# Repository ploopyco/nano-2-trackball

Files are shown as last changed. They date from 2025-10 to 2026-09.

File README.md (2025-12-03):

# The Ploopy Nano 2 Trackball

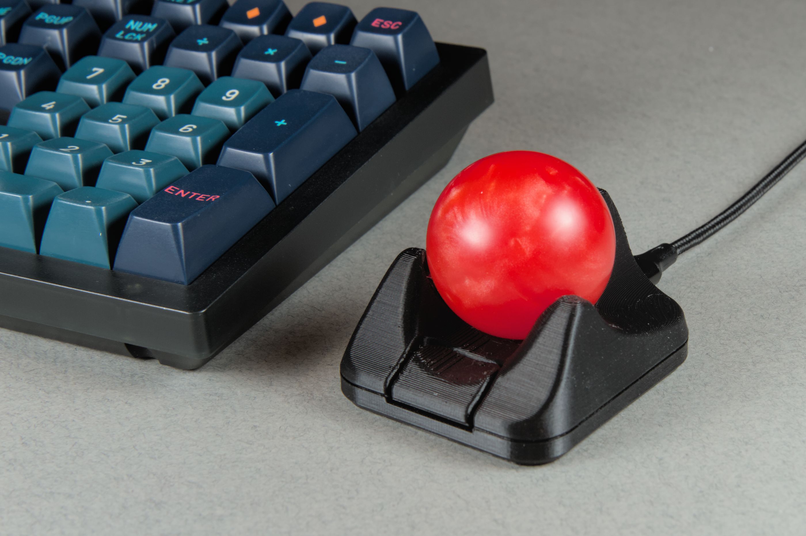
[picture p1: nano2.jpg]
The Ploopy Nano 2 Trackball


By some stroke of luck, you've made your way here. The Ploopy Nano 2 Trackball. Your life will never be the same.

This repository contains all of the design and production files necessary to make a Ploopy Nano 2 Trackball. We've also included some kick-ass documentation on how to get it made, assemble it, and program it [which you can find here](https://ploopyco.github.io/nano-2-trackball/).

What are you waiting for? Your new life awaits.

## QMK?!

Nano 2's bought from the [Ploopy store](https://ploopy.co/shop/nano-2-trackball/) come with QMK preloaded. [Check out the documentation](https://ploopyco.github.io/nano-2-trackball/) for instructions on how to load new firmware onto your device. (It's super easy!)

The firmware file that ships with all Nano 2's is included in this repository as well, as `firmwares/nano2_natural_dragscroll_toggle.uf2`.

## Under what license is this released?

As per QMK's licensing requirements, the firmware for the Ploopy Nano 2 Trackball is released under GPLv3. Hardware design files, including electronics and mechanical files, are released under OHL CERN v2-S. Check the respective directories for full license text.

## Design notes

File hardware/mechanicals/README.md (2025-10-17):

## Only one file? Where are the parts?

The STEP/STL files contain all of the plastic parts in one file. Doing it this way preserves the assembly information, showing how the parts are supposed to fit together, as well as the expected clearances between parts. It also bundles all of the parts for a given revision together, so there's no accidental mixing of parts from different revisions.

## How do I print this?

You'll need to split the parts in the file up before you can print them. Most slicers can do this; if you have a compatible printer we recommend PrusaSlic3r, since that's the one we use in-house and have checked.

Note that submitting this file to some 3rd party print services will cause confusion, as they are expecting one body instead of many. To do this, you can use PrusaSlic3r to split the parts and then export each separately as an STL.

## How can I use the included .3mf file?

The .3mf file was generated using PrusaSlicer v2.9. The job was generated for Prusa i3 MK2S/MK3S/MK3S+ printers. It assumes the use of PLA that is printable at 200-230C. If you have that PrusaSlicer version, such a printer, and such filament, then you're in a lot of luck! We use a .3mf job that is very similar to this one to print these parts on our printing farm.

If you do not, then using the included .3mf file is likely going to cause you a lot of headaches. If this is the case, the included .3mf file should be considered **as a reference only**. If you use it at all, it is recommended that you look at it to see what kinds of print settings we use (gyroid infill, 0.3mm layer height, part orientation, etc.). However, you should use your own slicing software to generate the .gcode files for your printer.

## Why don't you include a .gcode file?

For your safety. Uploading a .gcode file onto a printer can be extremely hazardous if that .gcode file wasn't specifically generated for that printer. We don't want to come anywhere near that sort of scenario, so we are not going to upload a .gcode file.

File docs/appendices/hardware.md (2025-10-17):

# Appendix C: Hardware

## Buying hardware from us

Getting all of the hardware on your own can be tricky because the parts you select may not fit perfectly. [That's why we sell fully-assembled Nano 2's](https://ploopy.co/shop/nano-2-trackball/). Here's why that's great for you:

- Everything is guaranteed to fit together perfectly
- Everything is guaranteed to work as intended
- You'll end up saving money - probably quite a bit of money - by not spending on extra parts

Your call. You'll sort it out.

## Getting your own hardware

This guide was a bit light on detail in the other sections, and that's because the hardware has to conform to many specifications. They'll all be listed here.

First, a complete list of all the hardware you'll need:

- \#2 3/8" screws, x2
- MR63ZZ roller bearings, x3
- Friction pads, x4
- 1.5" ball

We'll be going over all of them in detail. There will be mentions of *critical specifications*; if you're going to be sourcing your own parts, **you must get parts that conform to the critical specifications**. If you go off-menu, the parts will not fit the way that we intended when we designed the Nano 2. That might mean that your Nano 2 **doesn't work**.

Let's get cracking.

### Screws

Here are the critical specifications:

- \#2
- 3/8" length

## MR63ZZ roller bearings
Here are the critical specifications:

- MR63ZZ bearing
- 3mm inner diameter
- 6mm outer diameter
- 2.5mm thickness

### Friction pads

Here are the critical specifications:

- Circular shape
- Up to 3/4" diameter
- Up to 1/8" thickness
- Non-slip

## 1.5" ball

We use a 1.5-inch diameter (38.00) balls. Any ball that is within 0.5mm in diameter should work.

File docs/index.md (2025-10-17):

# Home

So, you want to build a Ploopy Nano 2 Trackball, eh? Or, maybe you want to replace some broken parts. Maybe you want to reprogram it. Or maybe you just want to know how it all works. No matter the motivation, this is the place to learn.

**Sourced the parts and itching to get it built?** --> Get started by going to the [assembly instructions](assembly-instructions.md).

**Looking to purchase your own Nano 2?** --> [Check out the Ploopy store](https://ploopy.co/shop/nano-2-trackball/).

**Building a Ploopy Nano 2 from scratch?** --> Get started by going to [Appendix A: Printed circuit boards](appendices/pcbs.md).

---

*Copyright (C) 2025 Ploopy Corporation. Permission is granted to copy, distribute and/or modify this document under the terms of the GNU Free Documentation License, Version 1.3 or any later version published by the Free Software Foundation; with no Invariant Sections, no Front-Cover Texts, and no Back-Cover Texts. A copy of the license is included in the section entitled "GNU Free Documentation License".*

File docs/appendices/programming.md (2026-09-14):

# Appendix D: QMK Firmware Programming

## Working with QMK

Ploopy devices are fairly easy to program and reprogram, thanks to the excellent work by all of the developers and maintainers of the [QMK firmware suite](https://github.com/qmk/qmk_firmware).

## Before you begin

If you have never used QMK before, go through [all of the steps in the QMK guide to set up your environment](https://docs.qmk.fm/#/newbs_getting_started).

QMK was built for keyboards, so you'll see lots of references to code that looks like the following:

`-kb <keyboard>`

Whenever you see that, use the following syntax:

`-kb ploopyco/nano_2`

and you'll be fine.

## Building the Ploopy device firmware

Using QMK MSYS or your compilation toolchain of choice, compile the firmware with the following command:

`qmk compile -kb ploopyco/nano_2/rev2_003 -km default`

For more details on building QMK firmware in general, see the [QMK firmware guide](https://docs.qmk.fm/#/newbs_building_firmware).

## Putting the Ploopy device into bootloader mode

Putting the Ploopy device into bootloader mode is very easy.

1. Unplug it from your computer.
2. Hold down the button on the Nano 2.
3. Plug the Ploopy device into your computer.
4. The computer should recognise that a mass storage device was just plugged in. Once this is done, you should be able to drag and drop files onto the Ploopy device, as if the board was a USB drive.

And that's it. While plugged in this way, the Ploopy device will accept new firmware.

If you want to upload a new firmware file (a ".uf2" file, like "ploopy_nano2_v42069" or something), just drag it into the folder, and it'll automatically install on the Ploopy device and restart itself.

Whenever you want to put new firmware onto the Ploopy device, go through these steps again.

**TIP**: If your firmware is in some kind of strange state and uploading new firmware isn't fixing it, try uploading [a flash nuke](https://learn.adafruit.com/getting-started-with-raspberry-pi-pico-circuitpython/circuitpython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) to the Nano 2 before flashing the new firmware. It wipes the memory of the Nano 2 completely clean, which can help clear a few types of errors.

## Putting the Ploopy device into bootloader mode if it's bricked

Putting the Ploopy device into bootloader mode if it's bricked is a bit more involved, but still doable.

1. Unplug it from your computer.
2. Open it by removing the screws in the Base and removing the Top.
3. Look for a pair of vias (gold-plated holes) on the board ([here's a photo](../img/bl.jpg)).
4. Get a paper clip (non-insulated, i.e. no plastic shit covering it) or a pair of tweezers, or some wire. Whatever you've got on hand that's metal.
5. Stick the paper clip or tweezers into the holes. You're trying to form an electrical connection between the two holes.
6. While you've got the two vias connected with your metal bridge, plug the Ploopy device into your computer.
7. The computer should recognise that a mass storage device was just plugged in. Once this is done, you should be able to drag and drop files onto the Ploopy device, as if the board was a USB drive. Feel free to remove the tweezers or paperclip at this point.

And that's it. While plugged in this way, the Ploopy device will accept new firmware.

## And that's it!

Happy customizing!

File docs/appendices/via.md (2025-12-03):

# Appendix E: Using VIA

The Nano 2's button can be customized using a web application called "VIA". Currently, a bit of additional work is necessary to get VIA to work, but it should only take about thirty seconds.

Begin by copying and pasting the following into a text file, saving it as *nano2.json*:

    {
      "name": "Ploopy Nano 2 Trackball",
      "vendorId": "0x5043",
      "productId": "0x4CE5",
      "matrix": {
        "rows": 1,
        "cols": 1
      },
      "customKeycodes": [
        {
          "name": "DPI Config",
          "title": "DPI Config",
          "shortName": "DPI"
        },
        {
          "name": "Drag Scroll",
          "title": "Drag Scroll",
          "shortName": "DragScl"
        }
      ],
      "layouts": {
        "keymap": [
          [
            {
              "h": 2
            },
            "0,0"
          ]
        ]
      }
    }

- Next, navigate to [the VIA web app](https://usevia.app), using **Microsoft Edge, Chrome, or Opera**. Any other browser that supports WebHID will work, too.
- Look at the top toolbar of the web application, and click the tab called *DESIGN*.
- Uncheck *Use V2 definitions (deprecated)*.
- Click *Load* and upload the *nano2.json* file that you saved on your computer.
- Plug in the Nano 2 if it wasn't plugged in already.
- Look at the top toolbar of the web application, and click the tab called *CONFIGURE*.
- Click *Authorize Device*. A modal window should pop up, and you should see the *Ploopy Nano 2 Trackball* as an option to connect. Do so now.

You should now see a representation of the buttons of the Nano 2 in the web app. You are now free to modify the button's functionality.

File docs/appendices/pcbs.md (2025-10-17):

# Appendix A: Printed circuit boards

## Buying boards from us
Getting the Ploopy boards made can be complex, and expensive, especially if you only need one set. [That's why we sell fully-assembled Nano 2's](https://ploopy.co/shop/nano-2-trackball/). Here's why that's great for you:

- You get a PCB with all components soldered
- The firmware is already programmed on the microcontroller, so you won't have to program it
- It'll cost a hell of a lot less than if you do a production run of PCBs just for yourself
- You won't have to order components and wait while they come in
- We guarantee that it works

Just something to consider. You're smart. You'll figure it out.

## Making your own boards

Want to make your own Ploopy Nano 2 Trackball boards? Great! Less work for us. Seriously, though, only choose this option if you know what you're doing. You don't want to embarrass yourself, do you?

### Step 1: Order the PCBs from a PCB production company

Here are the most important configurations you'll need to communicate to the company:

- 4 layers
- FR-4, TG 150-160 (basically, whatever the cheapest option is)
- 1.6mm thickness
- 6/6mil track/spacing distance
- 0.3mm minimum hole size
- ENIG surface finish, but you can go with HASL if you don't care about lead poisoning
- 1oz copper thickness for both outer and inner layers
- Choose whatever colours you want for solder mask and silkscreen; we like green solder mask and white silkscreen

If something is missing from here, it's not really important.

At some point, you'll have to upload design files to the production company. Use the [electronics source files](https://github.com/ploopyco/nano-2-trackball/tree/master/hardware/electronics) to generate manufacturing files (you'll have to convert them from their native Altium format if you're using some other platform). That should contain everything you need to get the boards made. If the production company rejects this package, however, you'll need to address the issue yourself.

### Step 2: Order the electronics components

All of the components are described in the schematics of the PCBs. Ordering the components is left as an exercise for the reader.

A complete list of all of the components can be found in the electrical design files.

### Step 3: Get the necessary tools

- PCB
- All of the electronics components
- A hot air rework tool
- Solder paste
- A printout of the schematics

### Step 4: Solder the components to the boards

Once you've got the PCBs and all of the components, print out the schematics. Use the schematics to match the reference designators on the PCBs to the reference designators on the schematics, and then get to soldering.

If you've never soldered surface mount components before, or want a refresher on how to solder, we recommend [this video on using an iron to solder surface mount components](https://www.youtube.com/watch?v=3NN7UGWYmBY), and [this video on using a hot-air soldering station](https://www.youtube.com/watch?v=c_Qt5CtUlqY).

### Step 5: All done!

Congrats, you finished assembling the electronics! Pat yourself on the back.

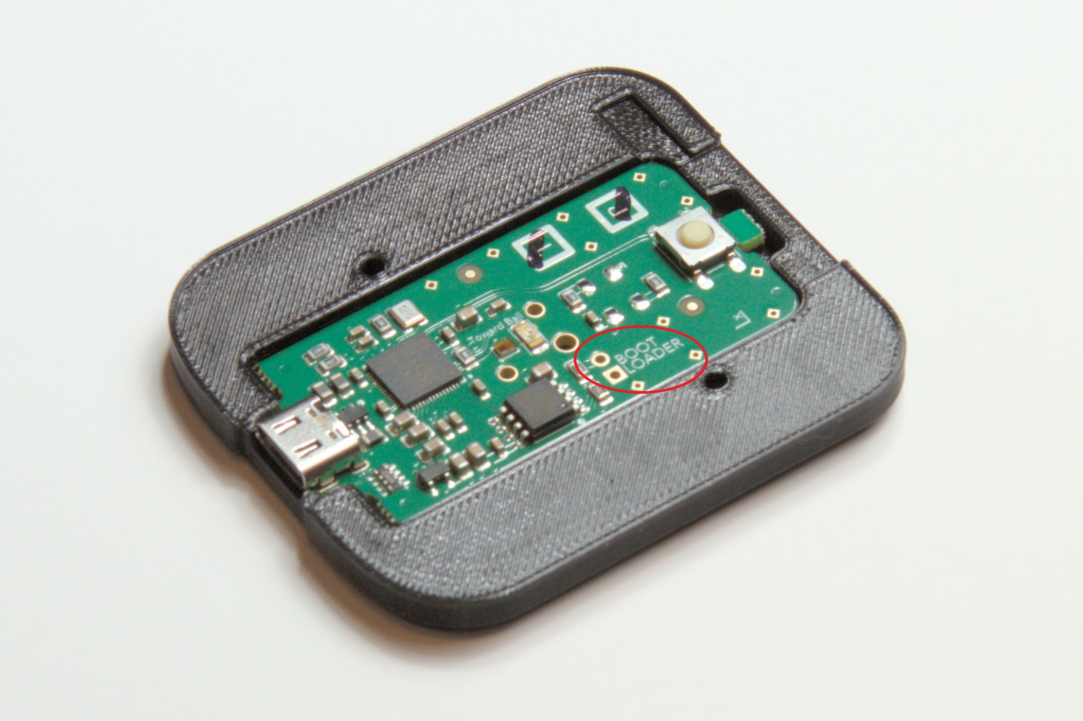
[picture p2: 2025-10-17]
docs/img/bl.jpg

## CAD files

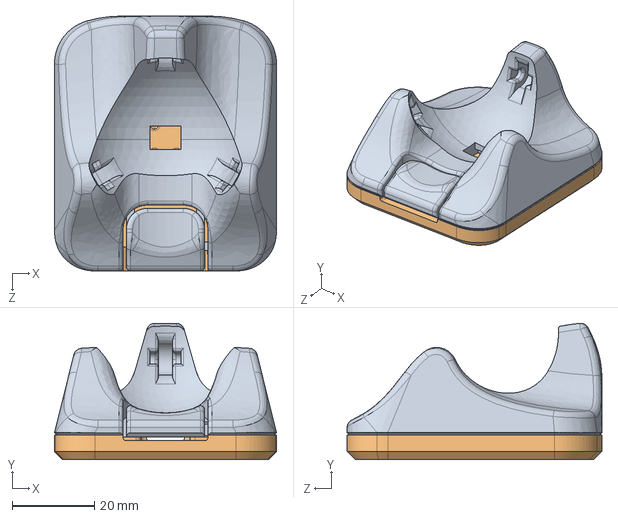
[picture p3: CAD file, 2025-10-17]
hardware/mechanicals/nano2.STEP
54.0 x 33.2 x 62.0 mm

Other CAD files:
hardware/mechanicals/nano2.3mf
hardware/mechanicals/nano2.STL

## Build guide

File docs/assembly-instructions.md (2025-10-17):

# Ploopy Nano 2 Trackball Assembly Instructions

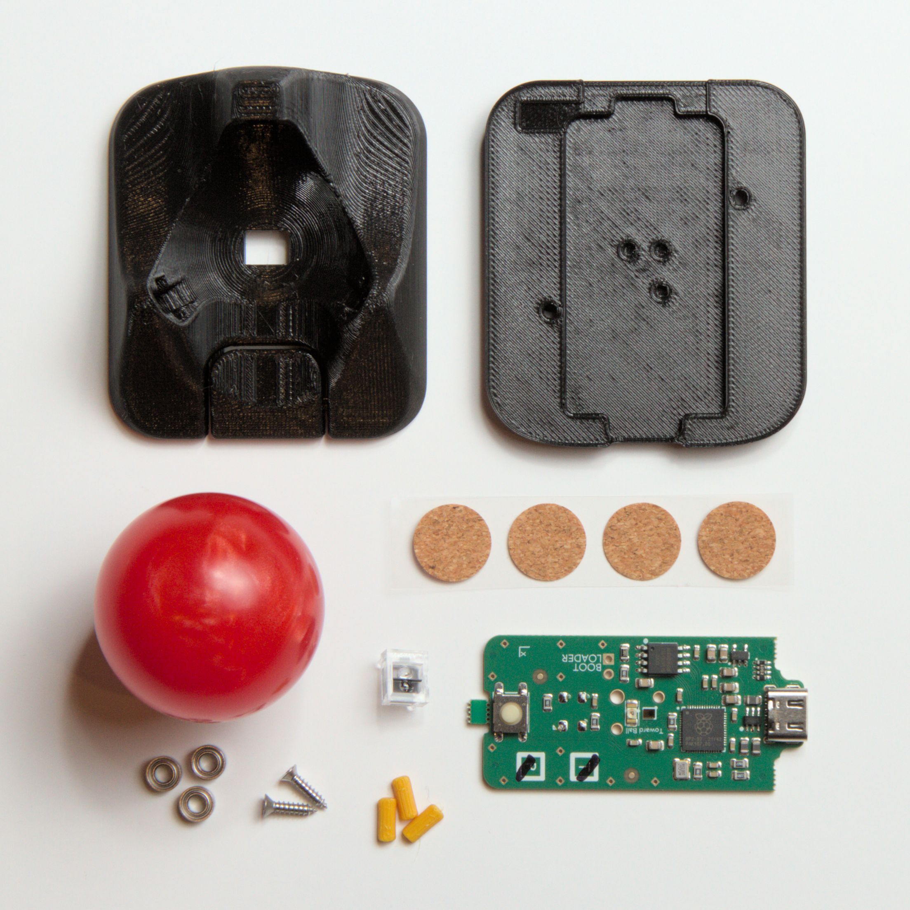
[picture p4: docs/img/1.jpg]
|  |
|:--:|
| *Figure 1: Everything you'll need* |

## Main Instructions

In this section, you'll go over how to build a Ploopy Nano 2 Trackball. This assumes you've sourced the parts yourself following the designs in this repository.

Here's how these instructions are structured*:

- 💡 Comments with a lightbulb are good information to know.
- ➡️ Comments with an arrow are commands. Execute them when you encounter them.
- ✅ Comments with a checkmark are verification steps. Check what they tell you to check, and if it's all good, move on.
- 📷 Comments with a camera are references to photos. Check the corresponding image for guidance.

Most steps have photos, so if you need some additional visual help, consult the images.

*\* Thanks to [schneems](https://github.com/schneems) for his [great suggestions on how to write documentation](https://github.com/ploopyco/headphones/issues/37).*

### Step 1

- ➡️ Get the Bottom, the PCB, and the PCB Optic. 📷 *See Figure 2.*

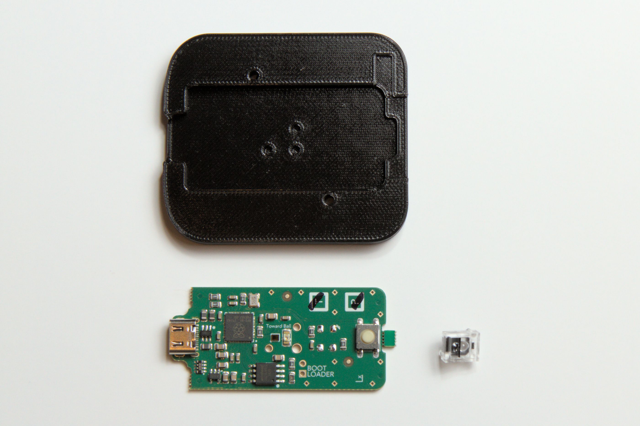
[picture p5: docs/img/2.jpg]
|  |
|:--:|
| *Figure 2: The Bottom, PCB, and PCB Optic* |

### Step 2

- 💡 In order to fit correctly, the PCB must be oriented correctly in the Bottom. 📷 *See Figure 3.*
- ➡️ Place the PCB into the Bottom.

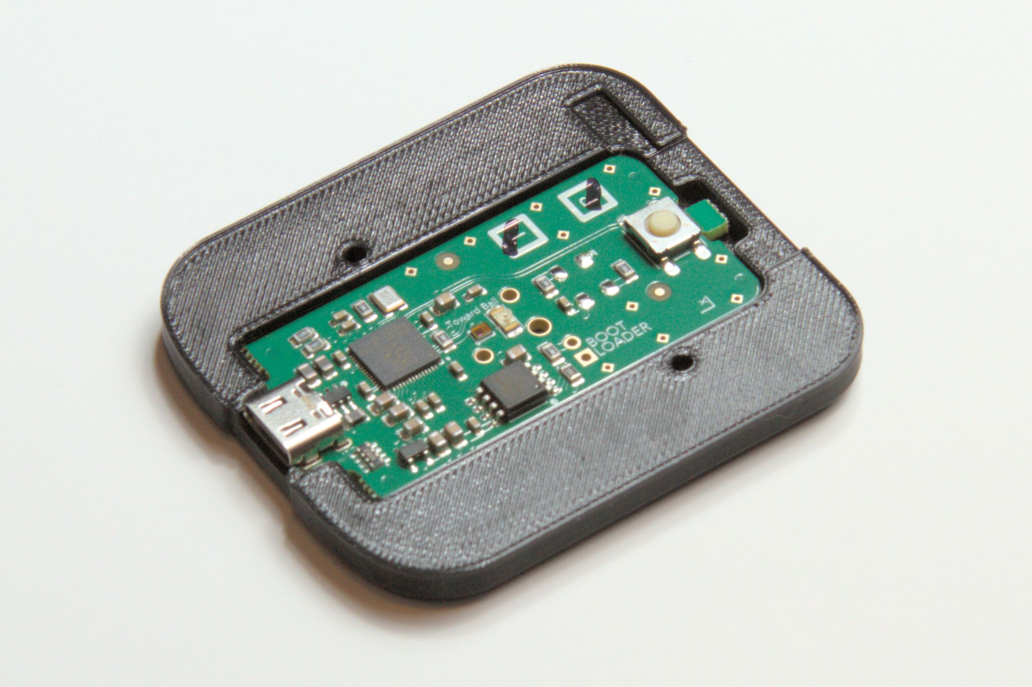
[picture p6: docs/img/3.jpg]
|  |
|:--:|
| *Figure 3: PCB correctly oriented in Bottom* |

### Step 3

- 💡 In order to fit correctly, the PCB Optic must be oriented correctly in the PCB. 📷 *See Figure 4 and Figure 5.*
- ➡️ Place the PCB into the Bottom.

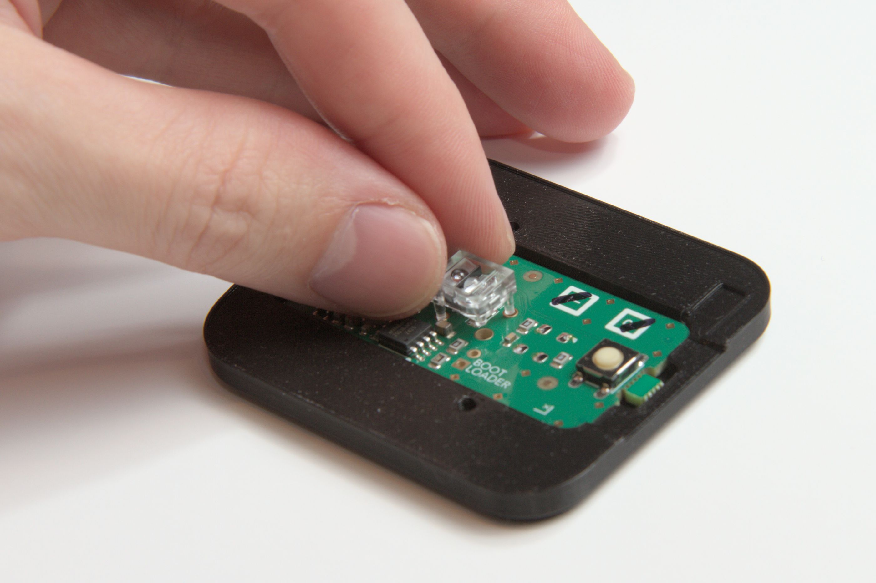
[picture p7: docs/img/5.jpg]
|  |
|:--:|
| *Figure 4: Preparing to insert PCB Optic* |

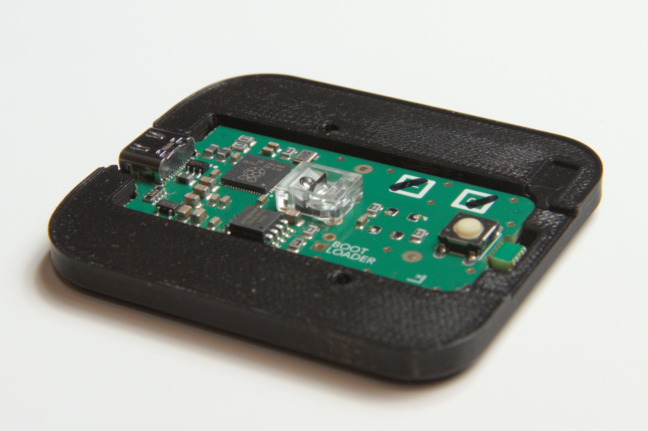
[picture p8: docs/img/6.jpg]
|  |
|:--:|
| *Figure 5: PCB Optic correctly oriented in PCB* |

### Step 4

- ➡️ Get the Top. 📷 *See Figure 6.*

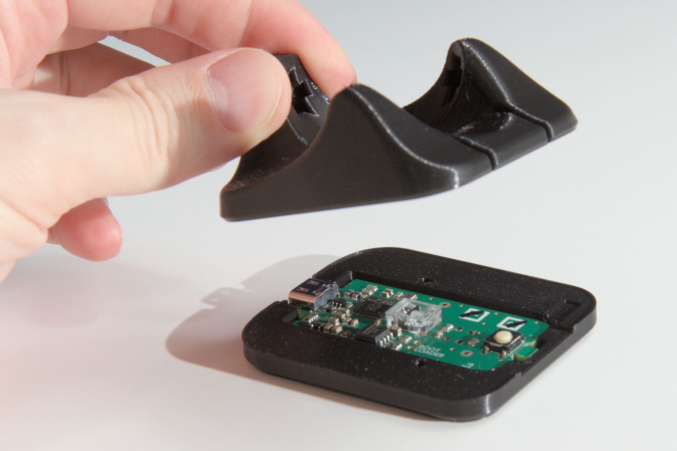
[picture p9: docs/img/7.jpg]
|  |
|:--:|
| *Figure 6: Top* |

### Step 5

- 💡 The Top has a flexible moving button mechanism. This mechanism must be oriented so that it is over the switch. 📷 *See Figure 6 again.*
- ➡️ Place the Top onto the Bottom assembly. 📷 *See Figure 7.*

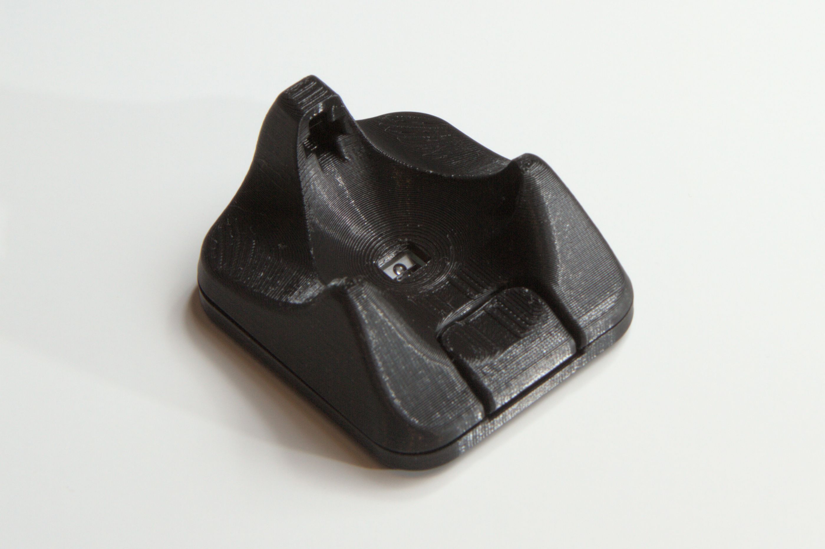
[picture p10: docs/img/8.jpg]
|  |
|:--:|
| *Figure 7: Top placed correctly on Bottom assembly* |

### Step 6

- ➡️ Get a #1 Phillips head screwdriver (or similar; you're looking for a small-ish screwdriver here).
- ➡️ Get the two screws. 📷 *See Figure 8.*
- ➡️ Screw in the two screws. 📷 *See Figure 9.*

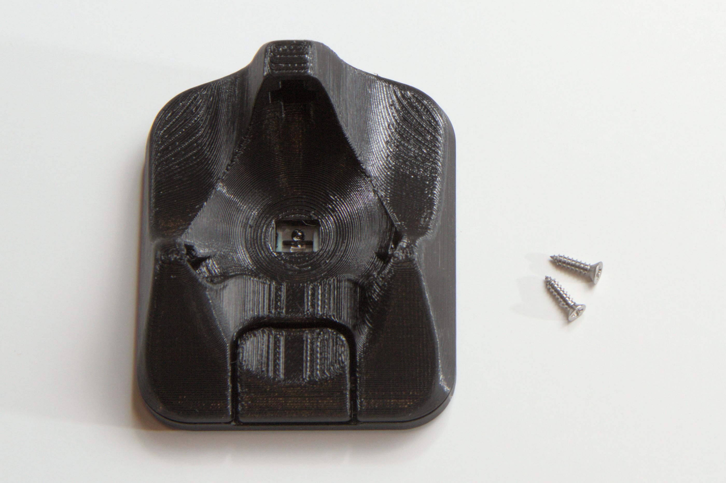
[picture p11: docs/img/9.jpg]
|  |
|:--:|
| *Figure 8: Two screws* |

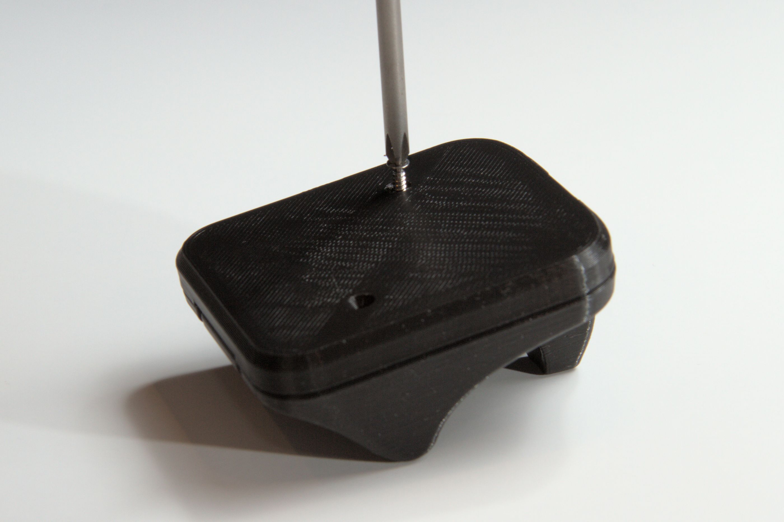
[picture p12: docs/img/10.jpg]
|  |
|:--:|
| *Figure 9: Screws being screwed down* |

### Step 7

- ➡️ Get the friction pads. 📷 *See Figure 10.*
- ➡️ Place the friction pads on the Bottom. 📷 *See Figure 11.*

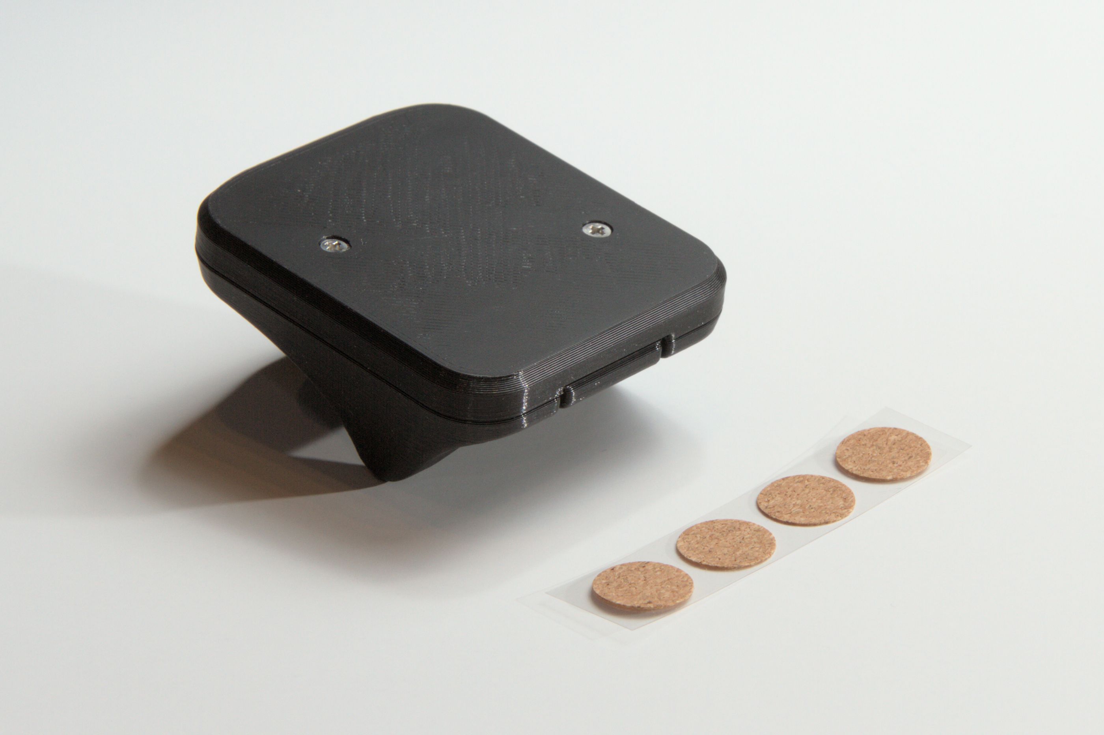
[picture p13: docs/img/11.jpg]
|  |
|:--:|
| *Figure 10: Four friction pads* |

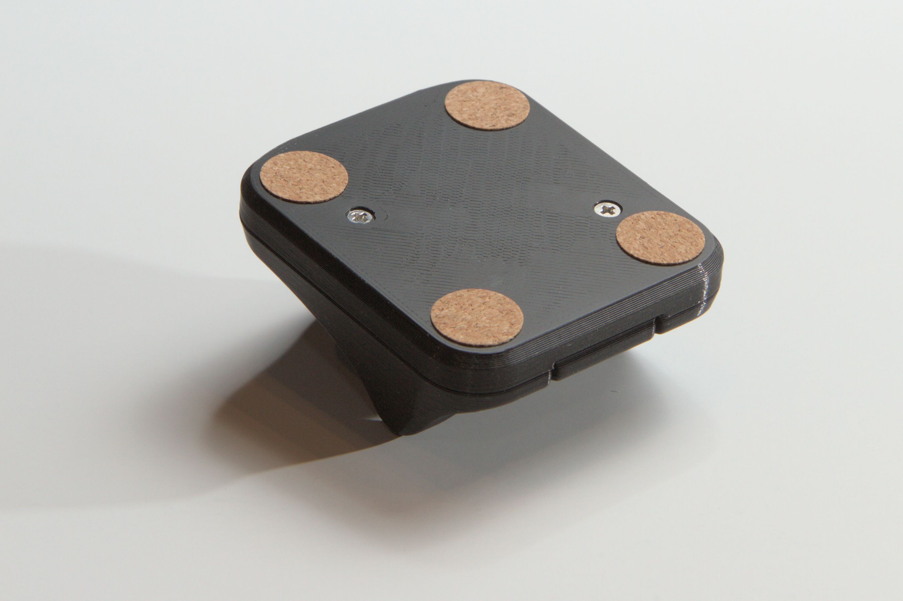
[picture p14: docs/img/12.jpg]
|  |
|:--:|
| *Figure 11: Four friction pads installed* |

### Step 8

- ➡️ Get 3x Roller Bearings, 3x Roller Bearing Dowels, and the Bearing Press Jig. 📷 *See Figure 12 for details.*
- ➡️ Insert a Roller Bearing and a Roller Bearing Dowel into the halves of the Bearing Press Jig. 📷 *See Figure 13 for details.*
- 💡 Pressing the halves of the Bearing Press Jig together may require a surprising amount of force.
- ➡️ Press the halves of the Bearing Press Jig together. 📷 *See Figure 14 for details.*
- ➡️ Remove the bearing from the Bearing Press Jig and repeat two more times for the other Roller Bearings. 📷 *See Figure 15 for details.*

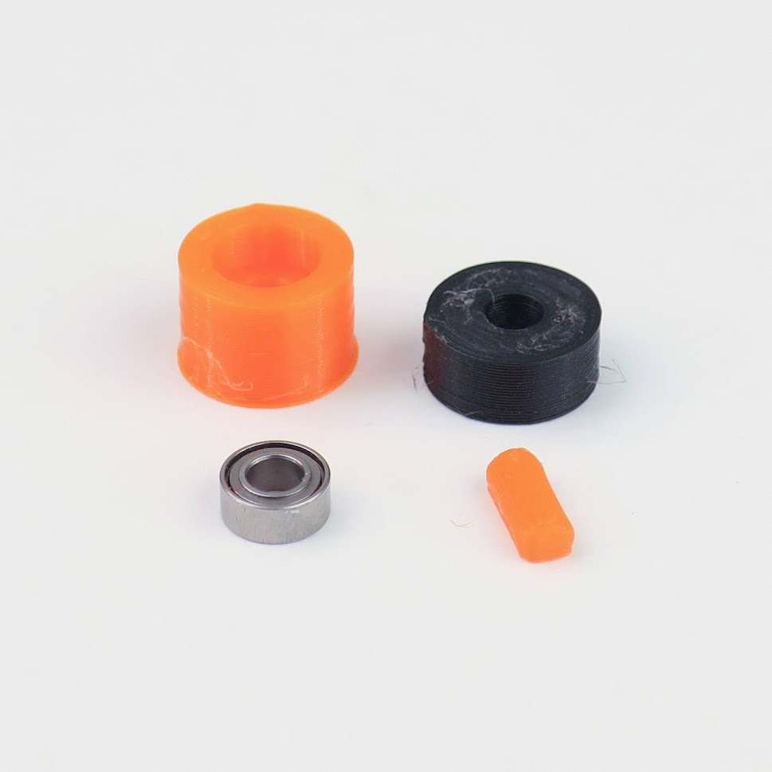
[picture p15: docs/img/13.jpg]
|  |
|:--:|
| *Figure 12: Roller Bearings, Roller Bearing Dowels, and the Bearing Press Jig* |

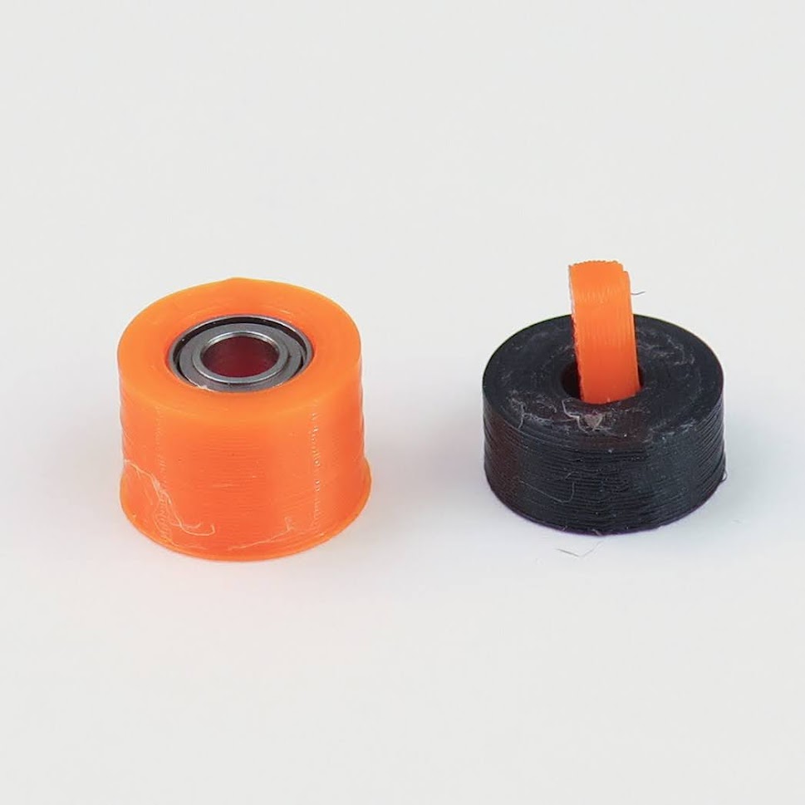
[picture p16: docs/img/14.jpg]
|  |
|:--:|
| *Figure 13: Roller Bearing and a Roller Bearing Dowel in the halves of the Bearing Press Jig* |

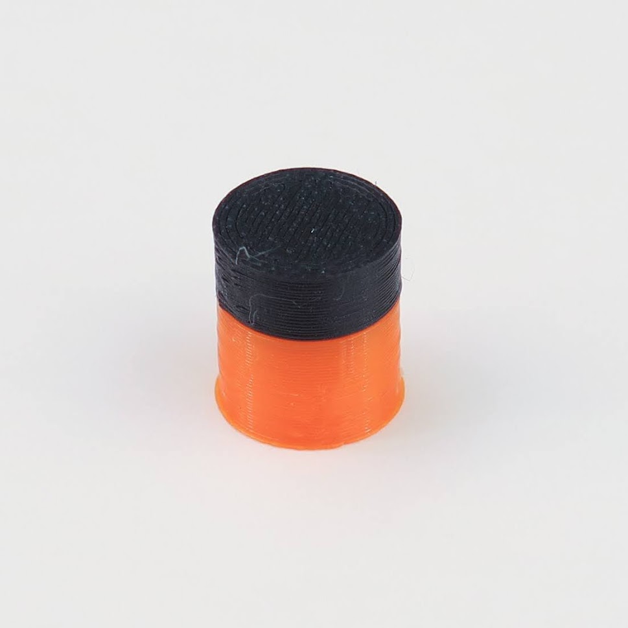
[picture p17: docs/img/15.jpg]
|  |
|:--:|
| *Figure 14: Halves of the Bearing Press Jig pressed together* |

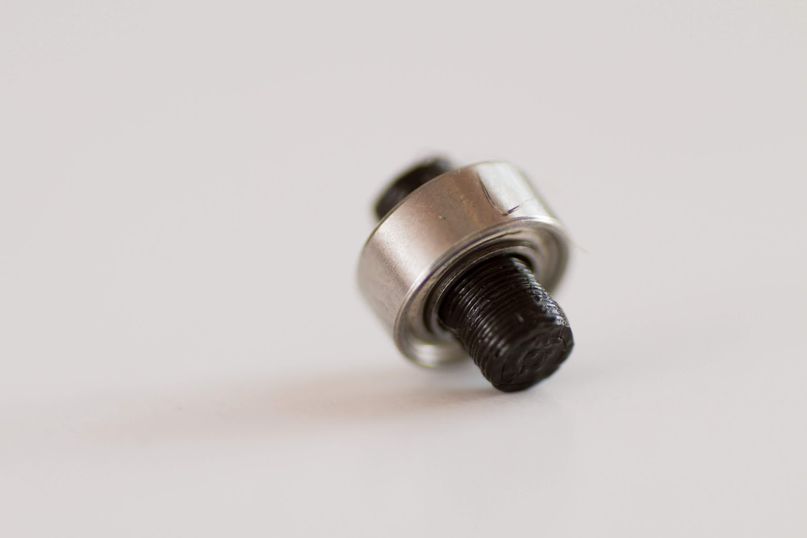
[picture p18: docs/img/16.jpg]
|  |
|:--:|
| *Figure 15: Completed Roller* |

### Step 9

- ➡️ Get the Top and 3x Rollers.
- 💡 Consider using needle nose pliers to press the Rollers into the Top as that will ensure that the Roller is fully seated.
- ➡️ Insert Rollers into the Top. 📷 *See Figure 16 for details.*
- 💡 If the Rollers aren't seated all the way, there's a good chance that tracking performance will be very bad.
- ✅ Ensure that the Rollers are pressed all the way into the Top, which may require quite a bit of force.

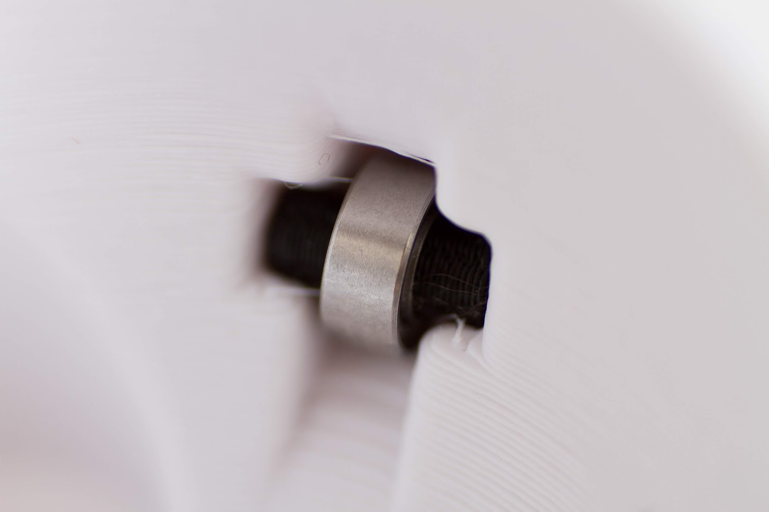
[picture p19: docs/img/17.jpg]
|  |
|:--:|
| *Figure 16: Roller inserted into Top* |

### Step 10

- ➡️ Insert the Ball. 📷 *See Figure 17 for details.*
- ➡️ Plug the Nano 2 into your computer.
- ✅ Check that moving the Ball moves the cursor.

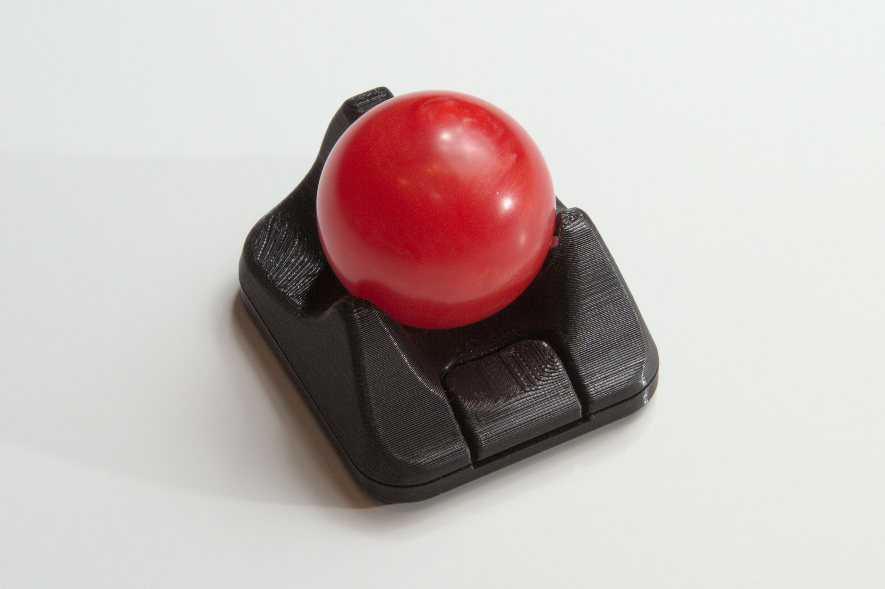
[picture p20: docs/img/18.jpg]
|  |
|:--:|
| *Figure 17: Ball inserted* |

### Step 16

- 💡 Congrats, you finished building the Ploopy Classic 2!
- 💡 It's done! Love it, use it, but don't you dare abuse it!

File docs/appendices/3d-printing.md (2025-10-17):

# Appendix B: 3D printed parts

## Buying 3D-printed parts from us

Not everyone has access to a 3D-printer. [That's why we sell fully-assembled Nano 2's](https://ploopy.co/shop/nano-2-trackball/). Here's why that's great for you:

- You get all of the 3D-printed parts, guaranteed free of manufacturing defects
- You won't waste time spending hours tweaking settings
- We guarantee it will fit together *perfectly*

Consider it. You're a smartie. You'll get there.

## Printing your own parts

So, you have a printer and want to print your own parts? Great! We don't have specific instructions, since every printer setup is different. All of the STLs are available, and if you need to make tweaks, you can alter the design files.

Here are the settings we use when we print parts. **Note that these settings have only been tested on the Prusa i3 MK2.5S and MK3S.** If you have another printer, you may need to tweak these settings.

- PLA. The geometry of many of the parts is quite complex; trying to use other materials may not result in success.
- 0.20mm layer height. You can go finer than this if you want, but we haven't tested that. Going coarser is not going to work; first, it's going to feel rough on your hand, and second, it won't accurately capture the necessary detail.
- No support material is necessary. If your slicer is showing support material, you didn't orient the parts correctly.
- Orient the pieces so that flat sides are on the build plate.
- We like gyroid for infill pattern, but anything is probably good. Cubic, rectilinear, whatever.
- We use 0.4mm nozzles. We haven't tested other nozzle sizes.

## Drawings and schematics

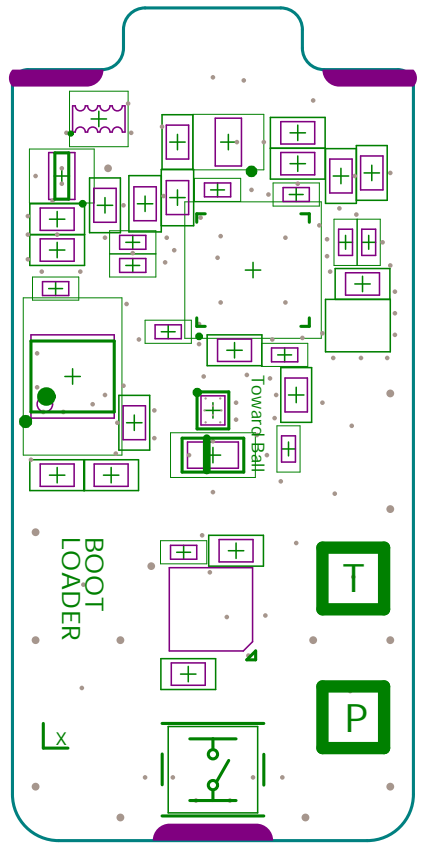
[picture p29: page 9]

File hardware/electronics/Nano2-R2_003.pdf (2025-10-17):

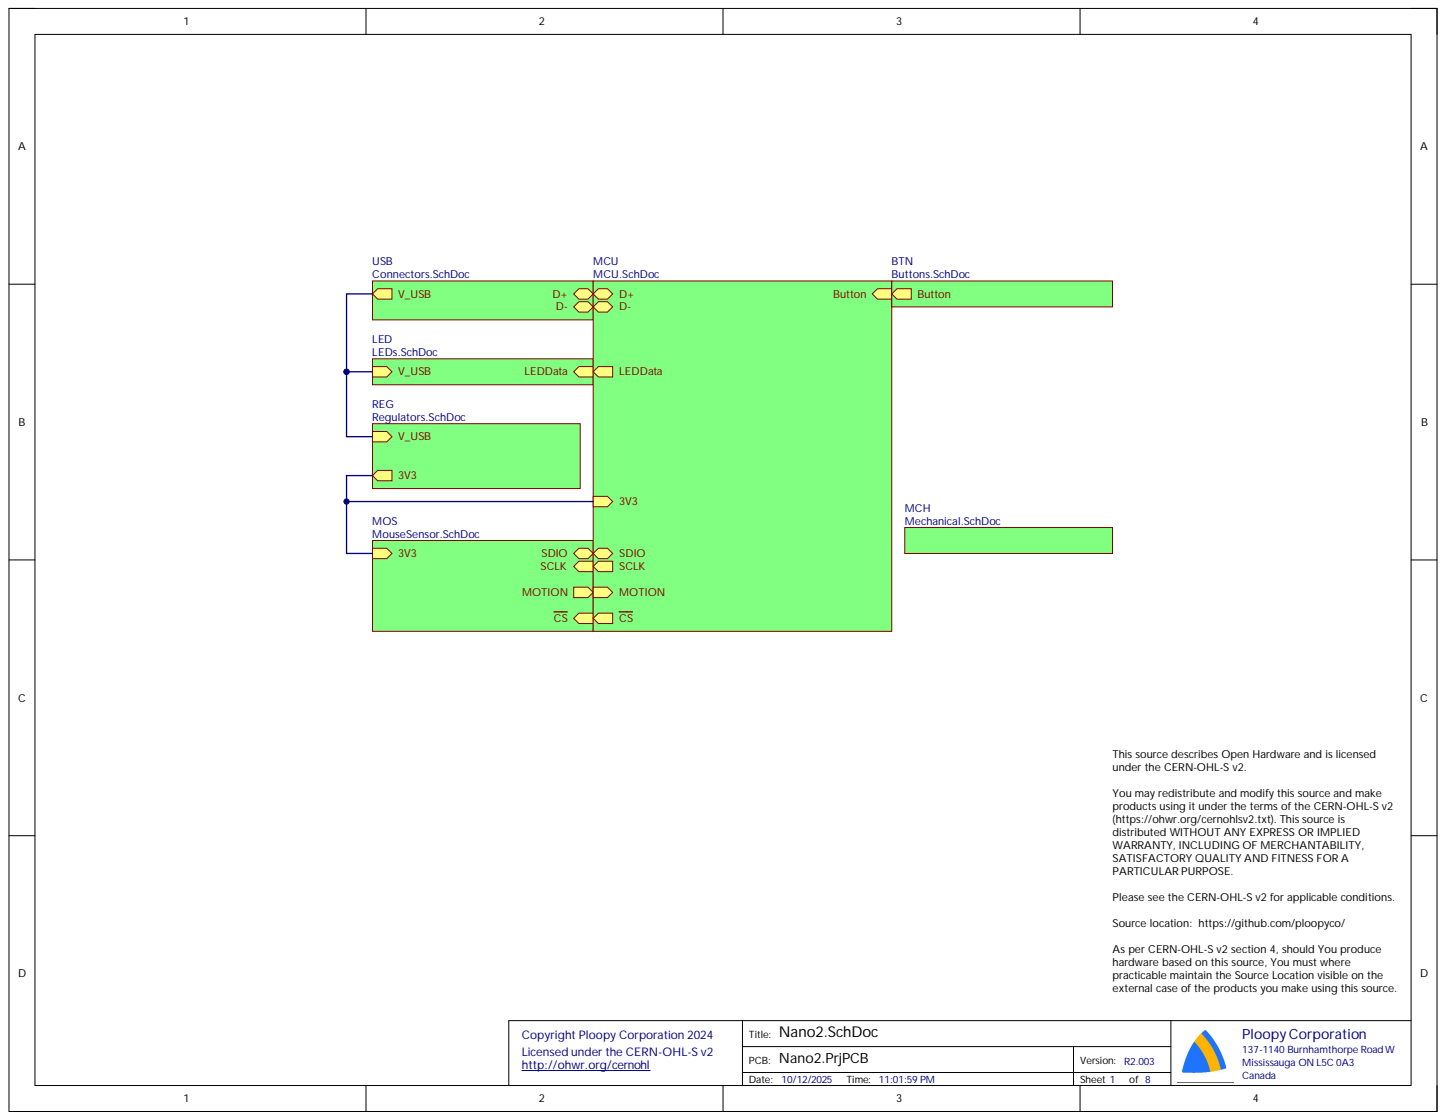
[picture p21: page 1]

This source describes Open Hardware and is licensed
under the CERN-OHL-S v2.

You may redistribute and modify this source and make
products using it under the terms of the CERN-OHL-S v2
(https://ohwr.org/cernohlsv2.txt). This source is
distributed WITHOUT ANY EXPRESS OR IMPLIED
WARRANTY, INCLUDING OF MERCHANTABILITY,
SATISFACTORY QUALITY AND FITNESS FOR A
PARTICULAR PURPOSE.

Please see the CERN-OHL-S v2 for applicable conditions.

Source location: https://github.com/ploopyco/

As per CERN-OHL-S v2 section 4, should You produce
hardware based on this source, You must where
practicable maintain the Source Location visible on the
external case of the products you make using this source.

Copyright Ploopy Corporation 2024
Licensed under the CERN-OHL-S v2
http://ohwr.org/cernohl

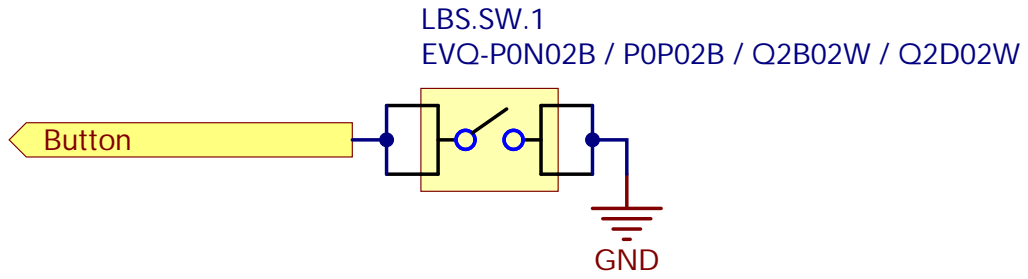
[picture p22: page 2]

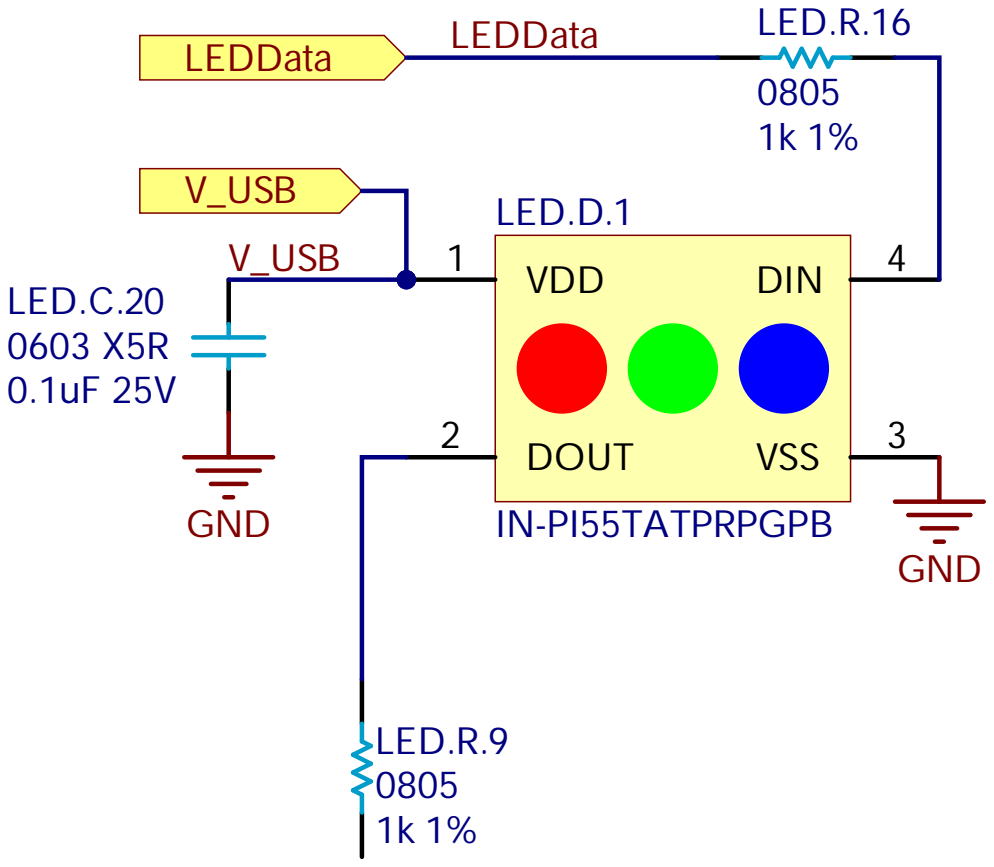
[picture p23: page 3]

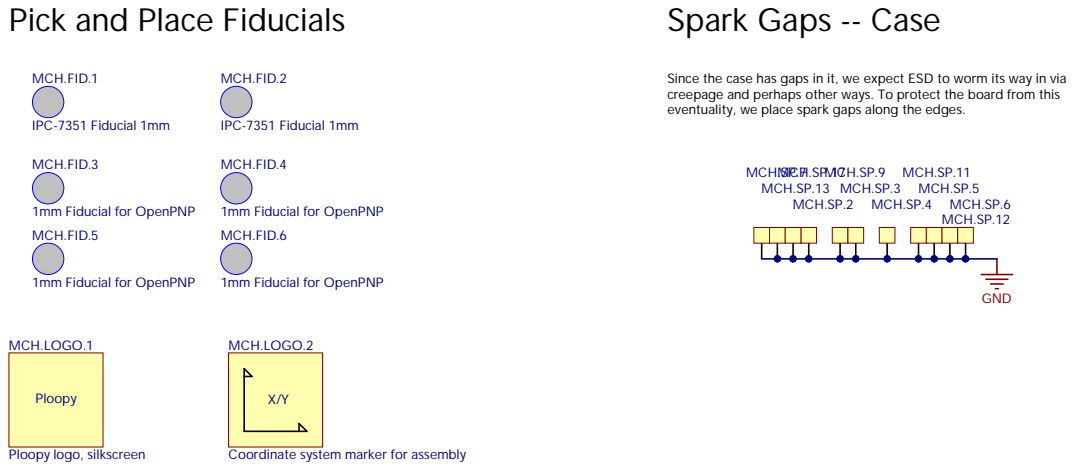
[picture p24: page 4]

Pick and Place Fiducials

Spark Gaps -- Case MCH.SP.7MCH.SP.2 MCH.SP.9 MCH.SP.3 MCH.SP.4 MCH.SP.1

Since the case has gap
creepage and perhap
eventuality, we place s

s other ways. To protect the board from this
park gap

pect ESD to worm its way in via

Coordinate system marker for assem

Cop
Licensed under the CE
http

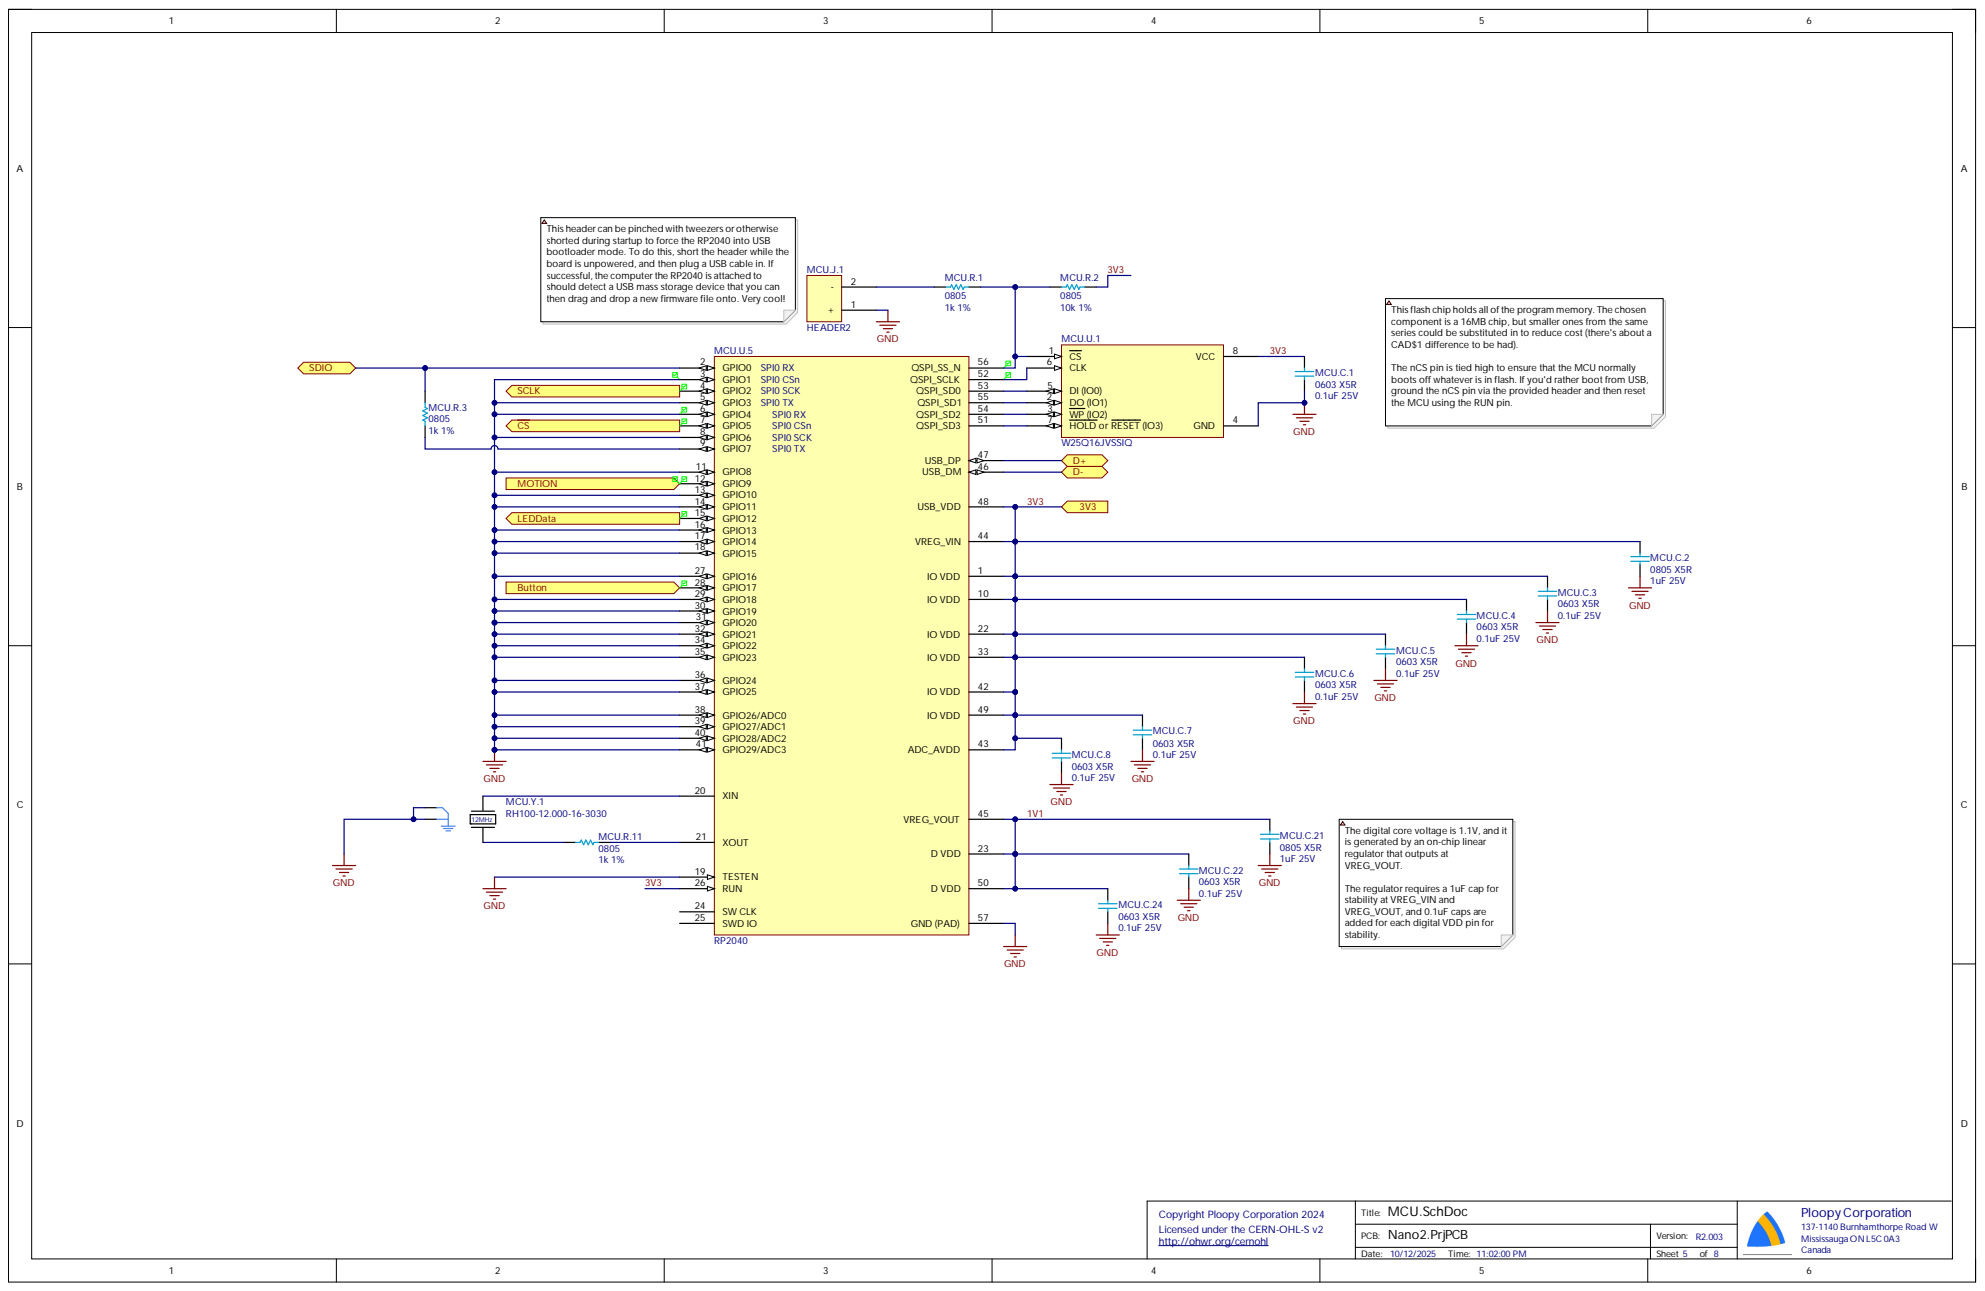
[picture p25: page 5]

Cop y rig h t Ploop y Cor pora tion 2 02 4 Lice n s e d u n d e r t h e CE R N -OH L -S v 2 h t t p : //ohwr .org /ce r noh l | T i t l e : MC U.S c h Doc | Plo opy C o rpo ra t i o n 1 3 7-1 1 40 B u r n h a m t hor p e Roa d W M i ssi ssa u g a O N L 5C 0A 3 C a n a d a

PC B : Nan o 2.P rj PC B | V e rsion : R 2 . 003

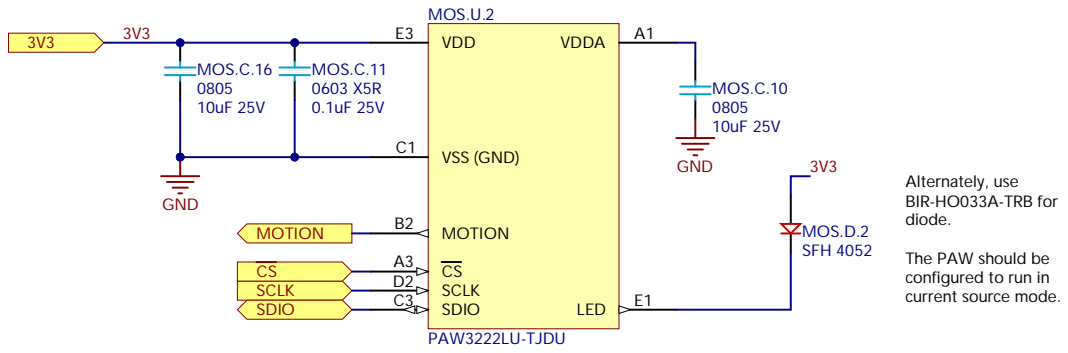
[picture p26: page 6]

Alternately, use BIR-HO033A-TR

diode. The PAW should be

configured to run in
current source mode.

Cop
Licensed under the CE
http

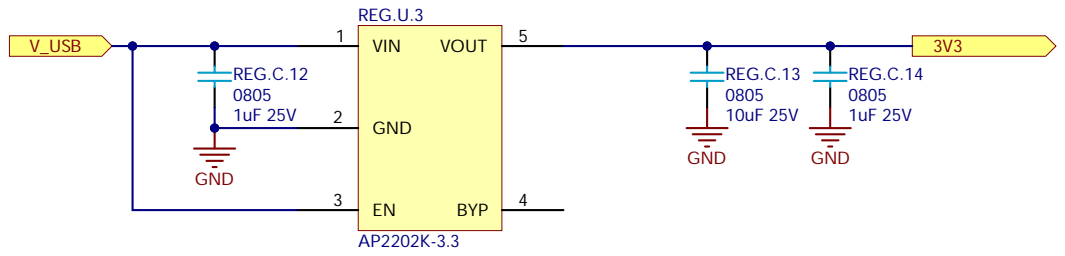
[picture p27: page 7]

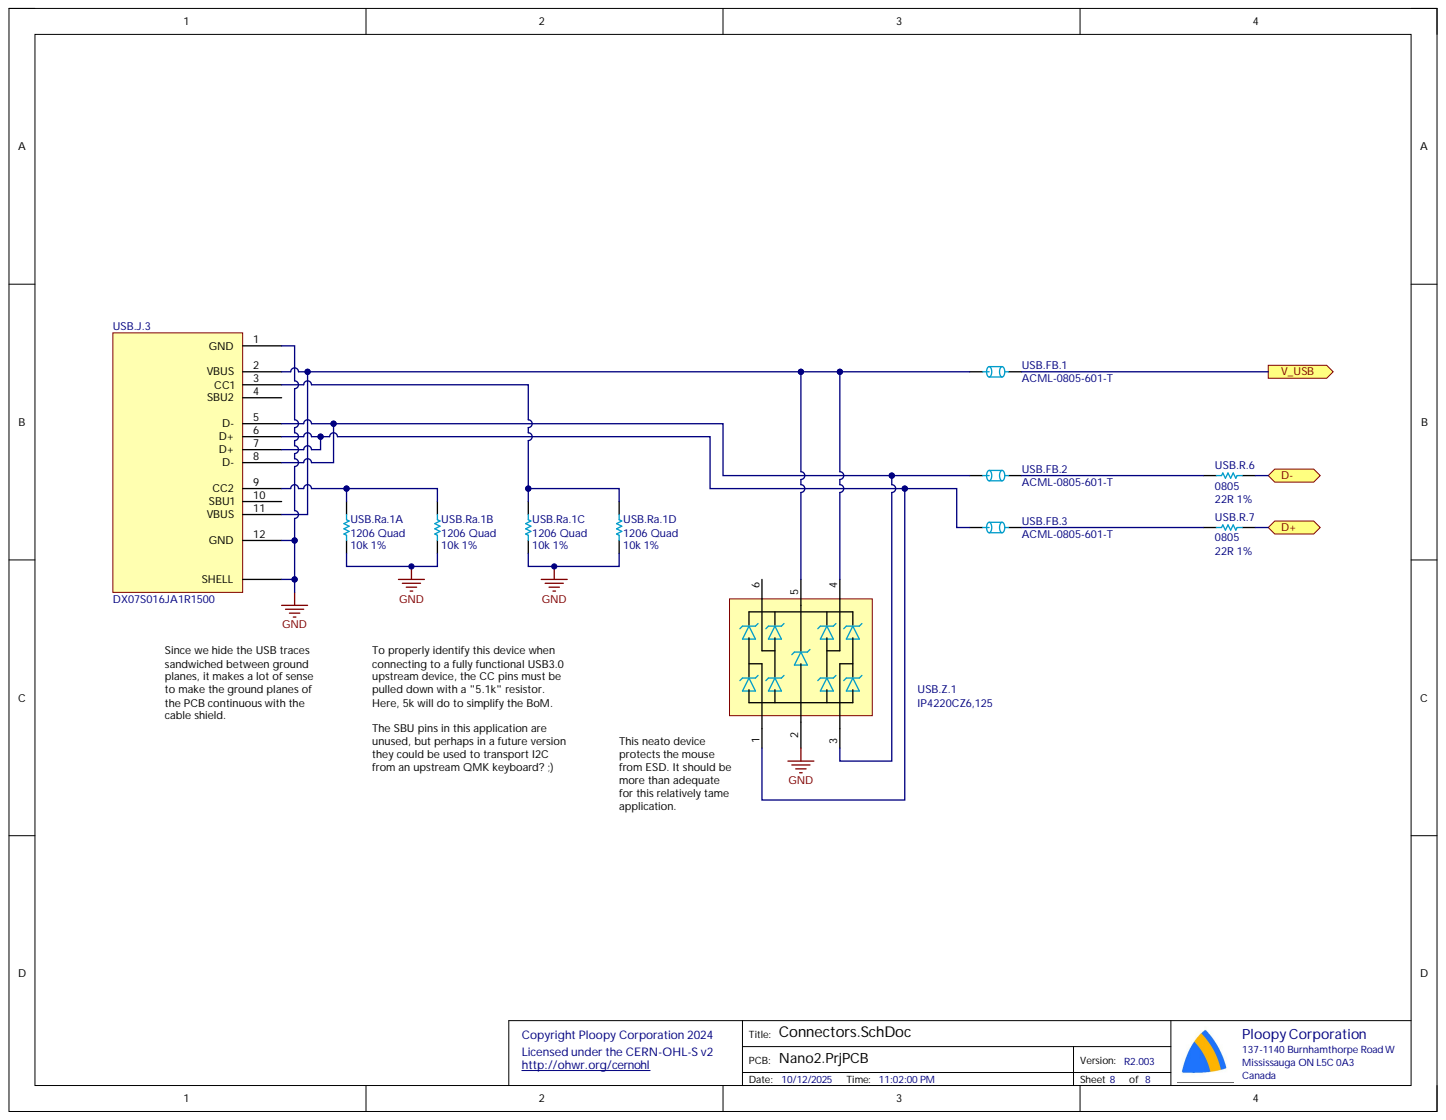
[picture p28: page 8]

Since we hide the USB traces sandwiched between ground planes, it makes a lot of sense

To properly identify this device when
connecting to a fully functional USB3.0
pulled down with a "5.1k" resistor.
Here, 5k will do to sim

to make the ground planes of
the PC
cable shield

The SB
unused, but perhap
they could be used to trans
from an up

U pins in this ap

This neato device protects the mouse

from ESD. It should be more than adequate

for this relatively tame

Cop
Licensed under the CE
http
